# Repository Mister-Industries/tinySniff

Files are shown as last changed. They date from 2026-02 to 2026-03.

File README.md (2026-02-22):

# tinySniff — Gas Sensor HAT for tinyCore

<div align="center">





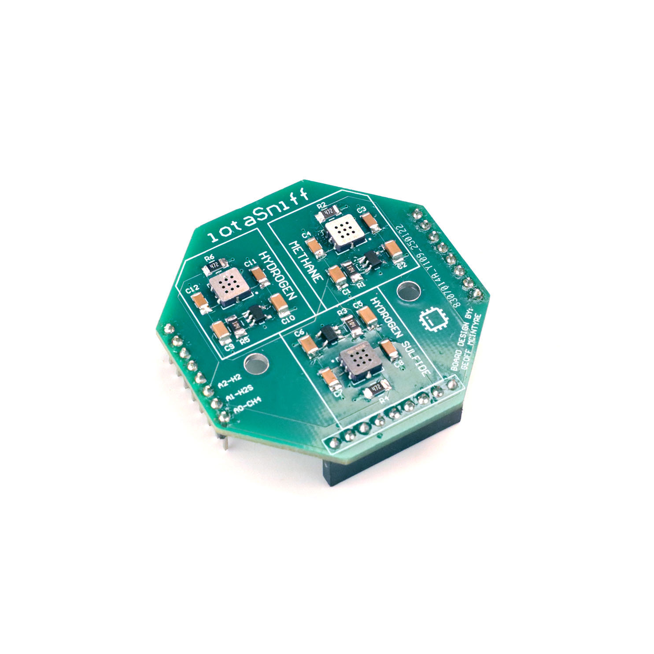
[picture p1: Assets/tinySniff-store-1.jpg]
tinySniff board


**A Gas/Air Quality (MEMS) sensor board for the [tinyCore](https://github.com/Mister-Industries/tinyCore) ESP32-S3 platform.**

Measures Methane, Hydrogen, and Hydrogen Sulfide. Great for air-quality and environmental monitoring projects.

[Purchase](https://mr.industries) · [Discord](https://discord.gg/hvJZhwfQsF) · [Documentation](https://tinydocs.cc/3_tiny-hats/tinysniff/)

</div>

---

## Pinout

tinySniff uses the following tinyCore GPIO pins. These are active whenever the HAT is mounted, so avoid assigning them to other peripherals in your own sketches.

### MEMS Sensor Pinouts

| Signal | GPIO | Description |
|---|---|---|
| H2 | A2 | GM-2021B (Hydrogen) Sensor |
| H2S | A1 | GM-602B (Hydrogen Sulfide) Sensor |
| CH4 | A0 | GM-402B (Combustible Gas / Methane) Sensor |

### How to open the Schematic (Altium)
The tinySniff design files are provided as an Altium Designer project. Altium Designer is a professional electronic design automation (EDA) software package.

To open the files:
1. Open [Altium Designer](https://www.altium.com/altium-designer) (requires a commercial license or the free Altium Viewer. Free student licenses are available).
2. Click **File > Open Project...** 
3. Navigate to the Hardware folder of this repository and select the `.PrjPcb` project file.
4. Once the project loads in the Projects panel, you can access:
   - **Schematic Editor** - Double-click the `.SchDoc` file to view the circuit design.
   - **PCB Editor** - Double-click the `.PcbDoc` file to view the board layout.

The project will open with all associated files (schematic, PCB, and libraries) ready to view and edit.

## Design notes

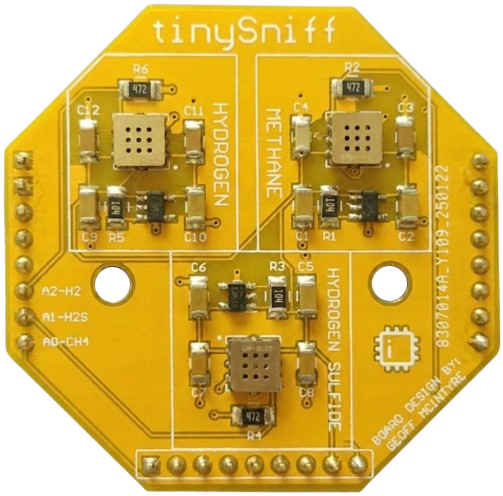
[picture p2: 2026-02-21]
Assets/tinySniff.png

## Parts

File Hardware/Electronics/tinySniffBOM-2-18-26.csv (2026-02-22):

Comment | Description | Designator | Footprint | LibRef | Quantity
1uF | MULTILAYER CERAMIC CAPACITORS MLCC - SMD/SMT 1UF 50V 1206 ROHS | C1, C2, C5, C6, C9, C10 | 1206_Passive_Capacitor | C_1uF_1206 | 6
100nF | 100nF ±5% 50V C0G 1206 Multilayer Ceramic Capacitors MLCC - SMD/SMT RoHS | C3, C4, C7, C8, C11, C12 | 1206_Passive_Capacitor | C_47nF_1206 | 6
AP2112K-2.6TRG1 | 600mA 1.8V LDO Regulator Enable SOT23-5 | IC1 | SOT95P285X140-5N | CMP-031-00006-1 | 1
AP2112K-1.8TRG1 | 600mA 1.8V LDO Regulator Enable SOT23-5 | IC2 | SOT95P285X140-5N | CMP-031-00006-1 | 1
AP2112K-2.5TRG1 | 600mA 1.8V LDO Regulator Enable SOT23-5 | IC3 | SOT95P285X140-5N | CMP-031-00006-1 | 1
100KOhm | 100kO ±1% 0.25W ±100ppm/? 1206 Chip Resistor - Surface Mount RoHS | R1, R3, R5 | 1206_Passive_Resitor | R_100KOhm_1206 | 3
4.7KOhm | 4.7kO ±1% 0.25W ±100ppm/? 1206 Chip Resistor - Surface Mount RoHS | R2, R4, R6 | 1206_Passive_Resitor | R_4.7k_1206 | 3
GM-402B | Generic MEMS footprint for GM series devices from Winsen | S1 | QFN127P500X500X155_HS-9N | CMP-010-00024-1 | 1
GM-602B | Generic MEMS footprint for GM series devices from Winsen | S2 | QFN127P500X500X155_HS-9N | CMP-010-00024-1 | 1
GMV-2021B | Generic MEMS footprint for GM series devices from Winsen | S3 | QFN127P500X500X155_HS-9N | CMP-010-00024-1 | 1

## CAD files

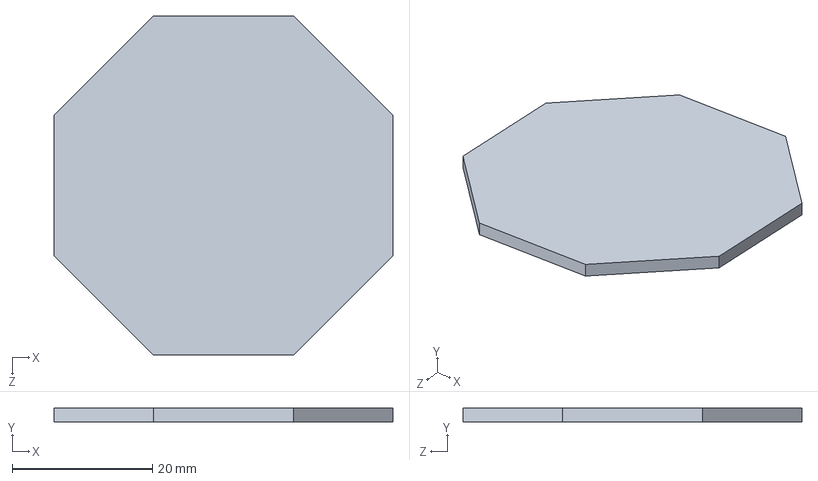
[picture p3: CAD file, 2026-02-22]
Hardware/SolidWorks/PCBShape.SLDPRT
48.3 x 2.00 x 48.3 mm

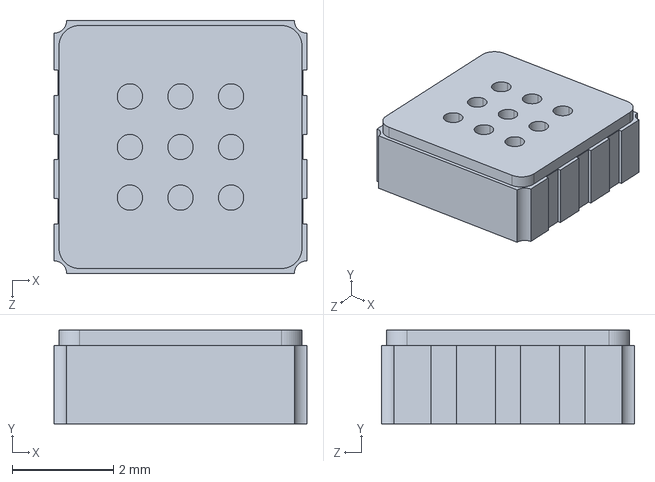
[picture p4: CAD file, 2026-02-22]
Hardware/STEP/GM-402B.STEP
5.00 x 1.85 x 5.00 mm

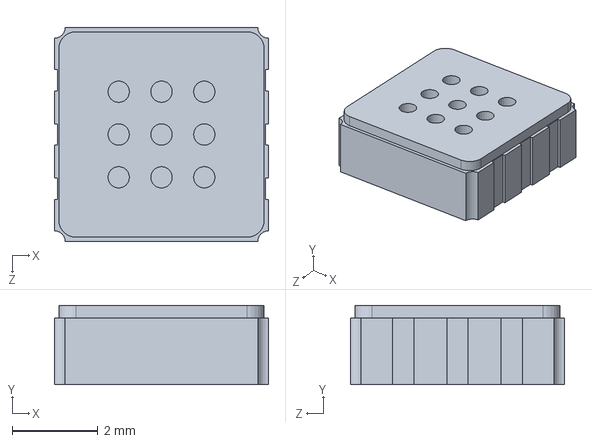
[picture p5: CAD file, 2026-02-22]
Hardware/SolidWorks/MEMSSensor.SLDPRT
5.00 x 1.85 x 5.00 mm

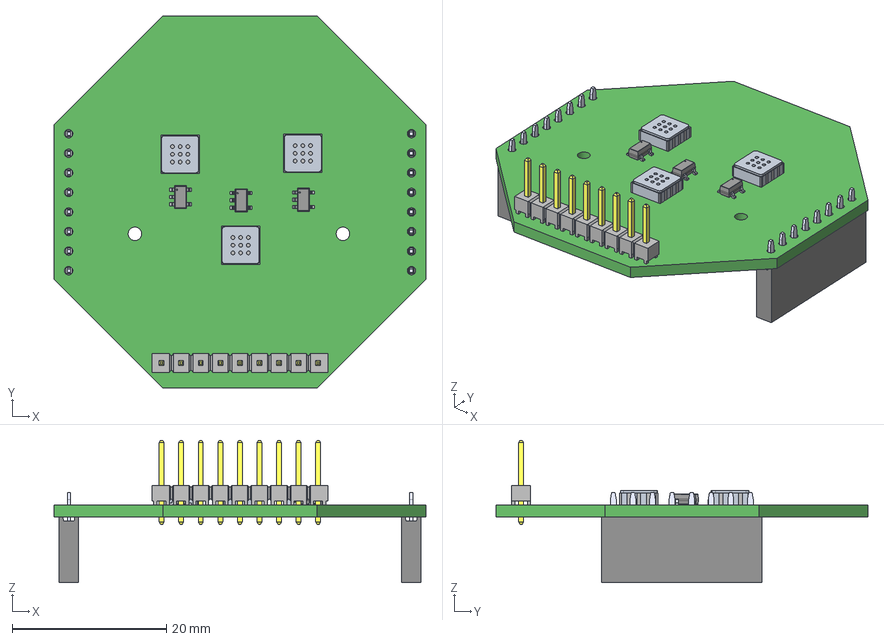
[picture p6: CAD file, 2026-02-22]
Hardware/STEP/tinySniff.step
48.3 x 48.3 x 18.5 mm
PinsArrayL x 3
PinsArrayR x 3
GM-402B x 3
Extruded x 3
T-1S6-07-HTSW-1--07-9-S
HTSW-109-07-G-S_body
PPTC081LFBN-RC--3DModel-STEP-56544 x 2

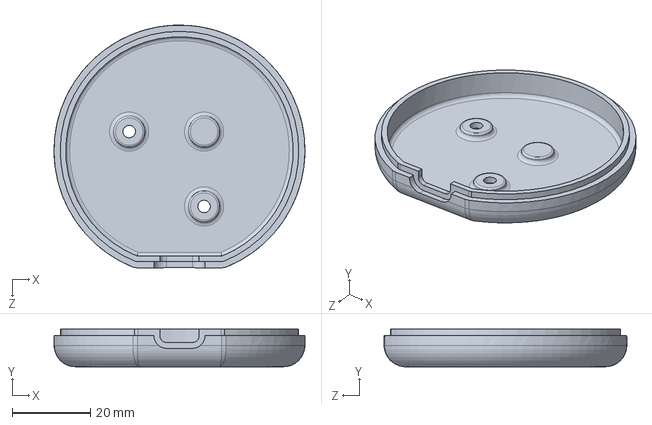
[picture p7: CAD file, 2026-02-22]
Hardware/SolidWorks/tinySniffEnclosureBottom.SLDPRT
64.0 x 9.60 x 61.9 mm

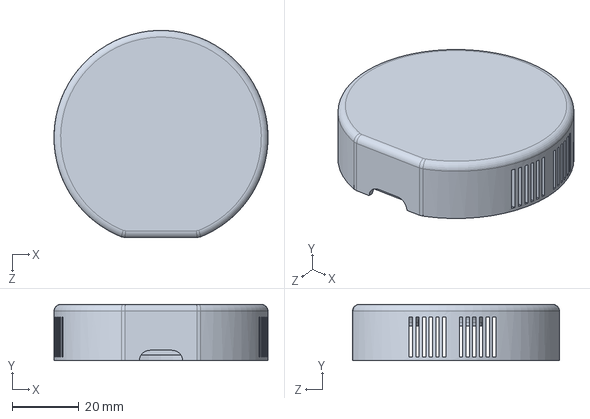
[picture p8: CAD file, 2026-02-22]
Hardware/SolidWorks/tinySniffEnclosureTop.SLDPRT
64.0 x 16.8 x 61.9 mm

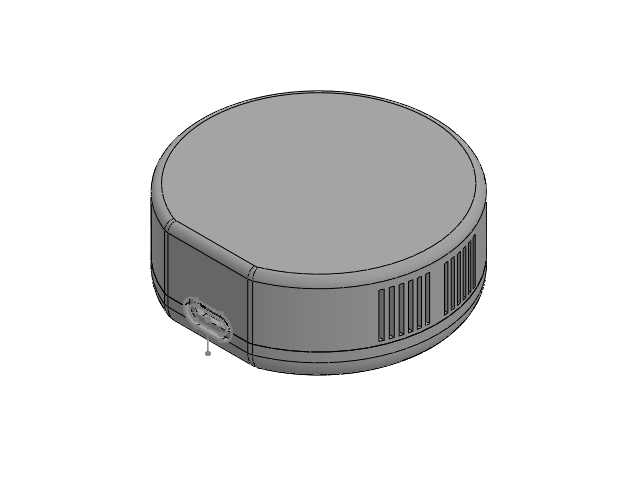
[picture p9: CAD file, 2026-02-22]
Hardware/SolidWorks/tinySniffEnclosure.SLDASM
tinySniffEnclosureBottom
tinySniffEnclosureTop
tinyCore-PCB
tinySniff
Part1^tinySniffEnclosure

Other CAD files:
Hardware/3D Printing/tinySniff.3mf
Hardware/3D Printing/tinySniffEnclosureBottom.STL
Hardware/3D Printing/tinySniffEnclosureTop.STL
Hardware/SolidWorks/PCBShape.DXF
Hardware/SolidWorks/tinySniff.SLDPRT

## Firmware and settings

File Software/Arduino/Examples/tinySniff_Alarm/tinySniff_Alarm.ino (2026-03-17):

/*
 * Project: tinySniff - tinySniff_Alarm
 * Author: Geoff McIntyre (w/ help from Claude)
 * Revision Date: 3/17/26
 * License: GNU General Public License v3.0
 *
 * Description:
 *   Monitors all three tinySniff gas sensors against configurable thresholds
 *   and sends an email alert when any channel exceeds its limit.
 *   Each threshold check uses a supersampled reading (average of
 *   SUPERSAMPLE_COUNT samples) so a single noisy ADC spike won't false-trigger.
 *
 *   Email is sent via SMTP using the ESP-Mail-Client library by Mobizt.
 *   Gmail works out of the box — see setup instructions below.
 *
 *   Gmail Setup (one-time):
 *   1. Enable 2-Step Verification on your Google account if not already on.
 *   2. Go to myaccount.google.com > Security > App Passwords.
 *   3. Create an app password (name it anything, e.g. "tinySniff").
 *   4. Copy the 16-character password — this goes into SMTP_PASSWORD below.
 *      (Your real Google password is NOT used here.)
 *   5. Fill in SMTP_SENDER_EMAIL and ALERT_RECIPIENT_EMAIL below.
 *
 *   Other SMTP providers (Outlook, SendGrid, Mailjet) work too —
 *   just change SMTP_HOST and SMTP_PORT accordingly.
 *
 *   Sensors:
 *     CH4  (Methane / Combustible Gas) — A0 — GM-402B
 *     H2S  (Hydrogen Sulfide)          — A1 — GM-602B
 *     H2   (Hydrogen)                  — A2 — GM-2021B
 *
 * Requirements:
 *   - Libraries: WiFi, ESP Mail Client (by Mobizt — install via Library Manager)
 *   - Hardware: tinyCore ESP32-S3 + tinySniff HAT + WiFi network
 *
 * Controls:
 *   [t]  Print current thresholds
 *   [s]  Print current sensor readings
 *   [a]  Toggle alarm armed / disarmed
 *   [e]  Send a test email
 *   [w]  Print WiFi status
 *   [?]  Show menu
 *   [Button]  Arm / Disarm alarm
 */

#include <Arduino.h>
#include <WiFi.h>
#include <ESP_Mail_Client.h>

// --- WIFI CREDENTIALS ---
#define WIFI_SSID  "your_ssid_here"
#define WIFI_PASS  "your_password_here"

// --- EMAIL CONFIG ---
// Gmail: use an App Password, NOT your real password (see setup above).
#define SMTP_HOST           "smtp.gmail.com"
#define SMTP_PORT           465                         // SSL — use 587 for TLS
#define SMTP_SENDER_EMAIL   "your.address@gmail.com"
#define SMTP_PASSWORD       "xxxx xxxx xxxx xxxx"       // 16-char Gmail App Password
#define ALERT_RECIPIENT_EMAIL  "recipient@example.com"  // Where alerts are sent

// --- PINS ---
#define PIN_CH4     A0
#define PIN_H2S     A1
#define PIN_H2      A2
#define PIN_BUTTON  RX

// --- ADC CONFIG ---
#define ADC_BITS  12

// --- SUPERSAMPLING CONFIG ---
// Threshold checks average this many reads — eliminates false triggers from
// single noisy ADC samples without adding meaningful latency (~1ms for 100).
#define SUPERSAMPLE_COUNT  100

// --- ALARM THRESHOLDS (raw ADC, 0-4095) ---
// Tune these after observing your clean-air baseline in the Serial Monitor.
// Supersampled readings are more stable than raw reads, so thresholds can
// be set tighter without nuisance trips.
#define THRESHOLD_CH4   1200   // GM-402B — Methane / Combustible Gas
#define THRESHOLD_H2S   1200   // GM-602B — Hydrogen Sulfide
#define THRESHOLD_H2    1200   // GM-2021B — Hydrogen

// --- ALARM CONFIG ---
#define SAMPLE_INTERVAL_MS   2000   // Check sensors every 2 seconds
#define ALERT_COOLDOWN_MS   60000   // Minimum ms between repeat alerts per channel (60s)
#define WIFI_RETRY_DELAY     5000

// --- GLOBALS ---
SMTPSession smtp;

bool alarmArmed = true;

unsigned long lastAlertTime_CH4 = 0;
unsigned long lastAlertTime_H2S = 0;
unsigned long lastAlertTime_H2  = 0;

unsigned long lastSampleTime  = 0;
unsigned long lastWifiAttempt = 0;

// Debounce
unsigned long lastDebounceTime = 0;
int lastButtonState = HIGH;

// ---------------------------------------------------------------
// Supersampling
// ---------------------------------------------------------------

float supersample(int pin) {
    long sum = 0;
    for (int i = 0; i < SUPERSAMPLE_COUNT; i++) sum += analogRead(pin);
    return (float)sum / SUPERSAMPLE_COUNT;
}

// ---------------------------------------------------------------
// WiFi
// ---------------------------------------------------------------

void connectWiFi() {
    if (WiFi.status() == WL_CONNECTED) return;
    Serial.printf("Connecting to %s", WIFI_SSID);
    WiFi.begin(WIFI_SSID, WIFI_PASS);
    int attempts = 0;
    while (WiFi.status() != WL_CONNECTED && attempts < 20) {
        delay(500);
        Serial.print(".");
        attempts++;
    }
    if (WiFi.status() == WL_CONNECTED) {
        Serial.printf("\nConnected! IP: %s\n", WiFi.localIP().toString().c_str());
    } else {
        Serial.println("\n[WARN] WiFi connection failed. Will retry.");
    }
}

// ---------------------------------------------------------------
// Email
// ---------------------------------------------------------------

// SMTP status callback — routes library debug output to Serial
void smtpCallback(SMTP_Status status) {
    Serial.println(status.info());
}

void sendAlertEmail(const char* gasName, float reading, int threshold) {
    if (WiFi.status() != WL_CONNECTED) {
        Serial.println("[WARN] Not connected — email not sent.");
        return;
    }

    Serial.printf("[Email] Sending alert for %s...\n", gasName);

    // Configure SMTP session
    Session_Config config;
    config.server.host_name = SMTP_HOST;
    config.server.port      = SMTP_PORT;
    config.login.email      = SMTP_SENDER_EMAIL;
    config.login.password   = SMTP_PASSWORD;
    config.login.user_domain = "";  // Leave empty for Gmail

    // Build message
    SMTP_Message message;
    message.sender.name  = "tinySniff";
    message.sender.email = SMTP_SENDER_EMAIL;
    message.subject      = "tinySniff Gas Alert";
    message.addRecipient("Alert Recipient", ALERT_RECIPIENT_EMAIL);

    char body[256];
    snprintf(body, sizeof(body),
        "tinySniff Gas Alert\n\n"
        "Sensor:    %s\n"
        "Reading:   %.1f (supersampled avg of %d reads)\n"
        "Threshold: %d\n\n"
        "Device is monitoring. Next alert for this channel\n"
        "will not be sent for %d seconds.",
        gasName, reading, SUPERSAMPLE_COUNT, threshold, ALERT_COOLDOWN_MS / 1000);

    message.text.content = body;
    message.text.charSet = "utf-8";

    smtp.debug(0); // Set to 1 for verbose SMTP debug output
    smtp.callback(smtpCallback);

    if (!smtp.connect(&config)) {
        Serial.printf("[Email] Connection failed: %s\n", smtp.errorReason().c_str());
        return;
    }
    if (!MailClient.sendMail(&smtp, &message)) {
        Serial.printf("[Email] Send failed: %s\n", smtp.errorReason().c_str());
    } else {
        Serial.printf("[Email] Alert sent: %s reading=%.1f\n", gasName, reading);
    }
    smtp.closeSession();
}

// ---------------------------------------------------------------
// Alarm Check
// ---------------------------------------------------------------

void checkAlarms() {
    float ch4 = supersample(PIN_CH4);
    float h2s = supersample(PIN_H2S);
    float h2  = supersample(PIN_H2);
    unsigned long now = millis();

    Serial.printf("[Monitor] CH4:%.1f  H2S:%.1f  H2:%.1f  (armed: %s)\n",
        ch4, h2s, h2, alarmArmed ? "YES" : "NO");

    if (!alarmArmed) return;

    if (ch4 > THRESHOLD_CH4 && (now - lastAlertTime_CH4 >= ALERT_COOLDOWN_MS)) {
        Serial.println("[ALARM] CH4 threshold exceeded!");
        sendAlertEmail("CH4 (Methane / Combustible Gas)", ch4, THRESHOLD_CH4);
        lastAlertTime_CH4 = now;
    }
    if (h2s > THRESHOLD_H2S && (now - lastAlertTime_H2S >= ALERT_COOLDOWN_MS)) {
        Serial.println("[ALARM] H2S threshold exceeded!");
        sendAlertEmail("H2S (Hydrogen Sulfide)", h2s, THRESHOLD_H2S);
        lastAlertTime_H2S = now;
    }
    if (h2 > THRESHOLD_H2 && (now - lastAlertTime_H2 >= ALERT_COOLDOWN_MS)) {
        Serial.println("[ALARM] H2 threshold exceeded!");
        sendAlertEmail("H2 (Hydrogen)", h2, THRESHOLD_H2);
        lastAlertTime_H2 = now;
    }
}

// ---------------------------------------------------------------
// Menu
// ---------------------------------------------------------------

void printThresholds() {
    Serial.println("\n--- Active Thresholds ---");
    Serial.printf("  CH4 (Methane):           %d / 4095\n", THRESHOLD_CH4);
    Serial.printf("  H2S (Hydrogen Sulfide):  %d / 4095\n", THRESHOLD_H2S);
    Serial.printf("  H2  (Hydrogen):          %d / 4095\n", THRESHOLD_H2);
    Serial.printf("  Supersample count:       %d reads/check\n", SUPERSAMPLE_COUNT);
    Serial.println("  Edit #define THRESHOLD_xxx to adjust.");
    Serial.println("-------------------------");
}

void printMenu() {
    Serial.println("\n--- tinySniff Alarm Menu ---");
    Serial.printf("  WiFi:     %s\n",
        WiFi.status() == WL_CONNECTED ? WiFi.localIP().toString().c_str() : "Not connected");
    Serial.printf("  Alarm:    %s\n", alarmArmed ? "ARMED" : "DISARMED");
    Serial.printf("  Alerting: %s\n", ALERT_RECIPIENT_EMAIL);
    Serial.println("[t]  Print thresholds");
    Serial.println("[s]  Print current sensor readings");
    Serial.println("[a]  Toggle alarm armed / disarmed");
    Serial.println("[e]  Send a test email");
    Serial.println("[w]  Print WiFi status");
    Serial.println("[?]  Show menu");
    Serial.println("[Button]  Arm / Disarm");
    Serial.println("----------------------------");
}

// ---------------------------------------------------------------
// Setup
// ---------------------------------------------------------------

void setup() {
    Serial.begin(115200);
    delay(2000);

    analogReadResolution(ADC_BITS);
    pinMode(PIN_CH4,    INPUT);
    pinMode(PIN_H2S,    INPUT);
    pinMode(PIN_H2,     INPUT);
    pinMode(PIN_BUTTON, INPUT_PULLUP);

    connectWiFi();

    Serial.println("tinySniff Alarm ready.");
    printMenu();
    printThresholds();
}

// ---------------------------------------------------------------
// Loop
// ---------------------------------------------------------------

void loop() {

    // 1. Reconnect WiFi if dropped
    if (WiFi.status() != WL_CONNECTED && (millis() - lastWifiAttempt >= WIFI_RETRY_DELAY)) {
        connectWiFi();
        lastWifiAttempt = millis();
    }

    // 2. Sample and check alarms
    if (millis() - lastSampleTime >= SAMPLE_INTERVAL_MS) {
        checkAlarms();
        lastSampleTime = millis();
    }

    // 3. Serial commands
    if (Serial.available()) {
        char cmd = Serial.read();
        switch (cmd) {
            case 't':
                printThresholds();
                break;
            case 's':
                Serial.printf("CH4:%.1f  H2S:%.1f  H2:%.1f\n",
                    supersample(PIN_CH4), supersample(PIN_H2S), supersample(PIN_H2));
                break;
            case 'a':
                alarmArmed = !alarmArmed;
                Serial.printf("Alarm %s\n", alarmArmed ? "ARMED" : "DISARMED");
                break;
            case 'e':
                Serial.println("Sending test email...");
                sendAlertEmail("TEST (ignore this)", 0.0f, 0);
                break;
            case 'w':
                Serial.printf("WiFi: %s  RSSI: %d dBm\n",
                    WiFi.status() == WL_CONNECTED
                        ? WiFi.localIP().toString().c_str()
                        : "disconnected",
                    WiFi.RSSI());
                break;
            case '?':
                printMenu();
                break;
        }
    }

    // 4. Button — arm/disarm (debounced)
    int reading = digitalRead(PIN_BUTTON);
    if (reading != lastButtonState) lastDebounceTime = millis();
    if ((millis() - lastDebounceTime) > 50) {
        static int buttonState = HIGH;
        if (reading != buttonState) {
            buttonState = reading;
            if (buttonState == LOW) {
                alarmArmed = !alarmArmed;
                Serial.printf("Alarm %s\n", alarmArmed ? "ARMED" : "DISARMED");
            }
        }
    }
    lastButtonState = reading;
}

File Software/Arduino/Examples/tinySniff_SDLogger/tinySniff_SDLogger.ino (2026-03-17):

/*
 * Project: tinySniff - tinySniff_SDLogger
 * Author: Geoff McIntyre (w/ help from Claude)
 * Revision Date: 3/17/26
 * License: GNU General Public License v3.0
 *
 * Description:
 *   Logs all three tinySniff MEMS gas sensors to a timestamped CSV
 *   file on the SD card. A new file (LOG_0001.CSV, LOG_0002.CSV, …)
 *   is created on each boot so previous sessions are never overwritten.
 *   Import the CSV into Excel, Google Sheets, or plot with Python.
 *
 *   Each logged measurement is the average of SUPERSAMPLE_COUNT raw ADC
 *   readings taken in rapid succession. This dramatically reduces ADC
 *   noise by averaging out random error — effectively giving you more
 *   effective bits of resolution for free.
 *
 *   A separate EMA (Exponential Moving Average) filtered column is also
 *   logged alongside the supersampled average. The EMA smooths slower
 *   trends across samples over time and is useful for spotting gradual
 *   gas buildup while ignoring momentary spikes.
 *
 *   CSV columns:
 *     Millis_ms | CH4_avg | CH4_ema | H2S_avg | H2S_ema | H2_avg | H2_ema
 *
 *   Sensors:
 *     CH4  (Methane / Combustible Gas) — A0 — GM-402B
 *     H2S  (Hydrogen Sulfide)          — A1 — GM-602B
 *     H2   (Hydrogen)                  — A2 — GM-2021B
 *
 * Requirements:
 *   - Libraries: SD, FS
 *   - Hardware: tinyCore ESP32-S3 + tinySniff HAT (SD card inserted)
 *
 * Controls:
 *   [s]  Force flush buffer to SD card now
 *   [p]  Print last 10 log entries to Serial
 *   [n]  Close current file and start a new one
 *   [?]  Show menu
 *   [Button]  Pause / Resume logging
 */

#include <Arduino.h>
#include <SD.h>
#include <FS.h>

// --- PINS ---
#define PIN_CH4     A0
#define PIN_H2S     A1
#define PIN_H2      A2
#define PIN_BUTTON  RX

// --- ADC CONFIG ---
#define ADC_BITS  12

// --- SUPERSAMPLING CONFIG ---
// Each logged value is the mean of this many rapid ADC reads.
// 100 samples takes ~1ms on ESP32-S3 — imperceptible in a 1s log interval.
#define SUPERSAMPLE_COUNT  100

// --- EMA FILTER CONFIG ---
// Alpha controls how quickly the EMA responds to new readings.
// Lower = smoother / slower response. Higher = faster / noisier.
//   0.05 = very smooth, good for detecting slow gas buildup
//   0.20 = moderate, tracks changes in a few seconds
//   0.50 = fast, follows readings closely
#define EMA_ALPHA  0.1f

// --- LOGGING CONFIG ---
#define LOG_INTERVAL_MS  1000   // One supersampled entry per second
#define FLUSH_EVERY_N    10     // Flush to SD every N entries
#define MAX_LOG_FILES    9999

// --- GLOBALS ---
File logFile;
String logFileName;
bool loggingPaused = false;
unsigned long entryCount   = 0;
unsigned long flushCounter = 0;
unsigned long lastLogTime  = 0;

// EMA state — initialized to -1 so we can seed on the first reading
float ema_ch4 = -1.0f;
float ema_h2s = -1.0f;
float ema_h2  = -1.0f;

// Debounce
unsigned long lastDebounceTime = 0;
int lastButtonState = HIGH;

// ---------------------------------------------------------------
// Supersampling — averages SUPERSAMPLE_COUNT rapid ADC reads
// ---------------------------------------------------------------

float supersample(int pin) {
    long sum = 0;
    for (int i = 0; i < SUPERSAMPLE_COUNT; i++) {
        sum += analogRead(pin);
    }
    return (float)sum / SUPERSAMPLE_COUNT;
}

// ---------------------------------------------------------------
// EMA filter — seeds on first call, then applies weighted average
// ---------------------------------------------------------------

float updateEma(float &ema, float newValue) {
    if (ema < 0.0f) {
        ema = newValue; // Seed with first real reading
    } else {
        ema = EMA_ALPHA * newValue + (1.0f - EMA_ALPHA) * ema;
    }
    return ema;
}

// ---------------------------------------------------------------
// File Management
// ---------------------------------------------------------------

String nextLogFileName() {
    for (int i = 1; i <= MAX_LOG_FILES; i++) {
        char name[20];
        snprintf(name, sizeof(name), "/LOG_%04d.CSV", i);
        if (!SD.exists(name)) return String(name);
    }
    return "/LOG_OVERFLOW.CSV";
}

bool openLogFile(const String& fileName) {
    logFile = SD.open(fileName, FILE_WRITE);
    if (!logFile) {
        Serial.printf("[ERROR] Could not open %s\n", fileName.c_str());
        return false;
    }
    // CSV header
    logFile.println("Millis_ms,CH4_avg,CH4_ema,H2S_avg,H2S_ema,H2_avg,H2_ema");
    logFile.flush();
    Serial.printf("Logging to: %s\n", fileName.c_str());
    return true;
}

// ---------------------------------------------------------------
// Menu
// ---------------------------------------------------------------

void printMenu() {
    Serial.println("\n--- tinySniff SD Logger Menu ---");
    Serial.printf("  File:       %s\n", logFileName.c_str());
    Serial.printf("  Entries:    %lu\n", entryCount);
    Serial.printf("  Status:     %s\n", loggingPaused ? "PAUSED" : "LOGGING");
    Serial.printf("  Supersamp:  %d reads/entry\n", SUPERSAMPLE_COUNT);
    Serial.printf("  EMA alpha:  %.2f\n", EMA_ALPHA);
    Serial.println("[s]  Flush buffer to card now");
    Serial.println("[p]  Print last 10 entries");
    Serial.println("[n]  Start a new log file");
    Serial.println("[?]  Show menu");
    Serial.println("[Button]  Pause / Resume logging");
    Serial.println("--------------------------------");
}

// ---------------------------------------------------------------
// Print last N entries from the active log file
// ---------------------------------------------------------------

void printLastEntries(int n) {
    if (logFile) logFile.flush();
    File f = SD.open(logFileName, FILE_READ);
    if (!f) { Serial.println("[ERROR] Could not read file."); return; }

    std::vector<String> lines;
    while (f.available()) lines.push_back(f.readStringUntil('\n'));
    f.close();

    Serial.printf("\n--- Last %d entries from %s ---\n", n, logFileName.c_str());
    int start = max(0, (int)lines.size() - n);
    for (int i = start; i < (int)lines.size(); i++) Serial.println(lines[i]);
    Serial.println("---");
}

// ---------------------------------------------------------------
// Setup
// ---------------------------------------------------------------

void setup() {
    Serial.begin(115200);
    delay(2000);

    analogReadResolution(ADC_BITS);
    pinMode(PIN_CH4,    INPUT);
    pinMode(PIN_H2S,    INPUT);
    pinMode(PIN_H2,     INPUT);
    pinMode(PIN_BUTTON, INPUT_PULLUP);

    if (!SD.begin()) {
        Serial.println("[ERROR] SD mount failed. Insert a card and reset.");
        while (1) delay(500);
    }
    Serial.println("SD mounted.");

    logFileName = nextLogFileName();
    if (!openLogFile(logFileName)) while (1) delay(500);

    Serial.println("tinySniff SD Logger ready.");
    printMenu();
}

// ---------------------------------------------------------------
// Loop
// ---------------------------------------------------------------
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

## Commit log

2026-02-22 Added Hardware Folder
    [GM-402B.STEP, MEMSSensor.SLDPRT, PCBShape.DXF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]
2026-02-22 Added Altium Source Files
    [tinySniff.PcbDoc, tinySniff.PrjPcb, tinySniff.SchDoc]
2026-02-22 Update README with tinySniff sensor details
    Added detailed information about the tinySniff gas/air quality sensor board, including pinout and instructions for opening the schematic in Altium Designer.
2026-02-22 Correct MEMS Sensors heading to MEMS Sensor Pinouts

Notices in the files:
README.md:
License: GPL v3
